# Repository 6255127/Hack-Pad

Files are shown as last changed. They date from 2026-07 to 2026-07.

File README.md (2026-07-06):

# Hackpad

A custom 3x4 macro keyboard I built from scratch - schematic, PCB, 3D printed case, and firmware, all done by me as a portfolio/hackathon project. Built around an Arduino Nano RP2040 Connect, with a rotary encoder, OLED status screen, and per-key RGB backlighting.

## Features
- 3x4 key matrix (12 keys)
- rotary encoder for scroll/navigation
- 0.91" OLED showing current layer, last key pressed, and time (synced over wifi)
- SK6812 addressable LEDs under each key
- two layers - numpad mode and a shortcuts mode (copy/paste/undo/save/etc)
- wired usb keyboard (bluetooth planned later, board already supports it)

---

## 1. Schematic

Designed in KiCad. Went through a few pin conflicts along the way (accidentally put the LED data line on the I2C bus at one point) before landing on the final wiring.



---

## 2. PCB routing

Routed as a 2-layer board - rows on the bottom copper, columns on top, vias where they cross. Ran into a mixed-up switch numbering issue during routing that caused some real weird ratsnest jumps, fixed by re-checking every switch against the row/column table by hand.



---

## 3. 3D case

Modeled in Fusion 360 / Onshape, sandwich-mount style. Bottom half holds the PCB and MCU, top half is the switch plate with cutouts for keycaps, the encoder, and the OLED window. Top plate designed to be printed in clear/frosted material so the LEDs glow through it.



---

## 4. Firmware

Written in Arduino for the Nano RP2040 Connect. Handles matrix scanning, encoder input, LED feedback, OLED display, and layer switching (numpad vs shortcuts) via the encoder click.



---

## To-do
- bluetooth (board already has the chip, just needs the firmware side)
- battery + charging circuit
- silkscreen art on the back

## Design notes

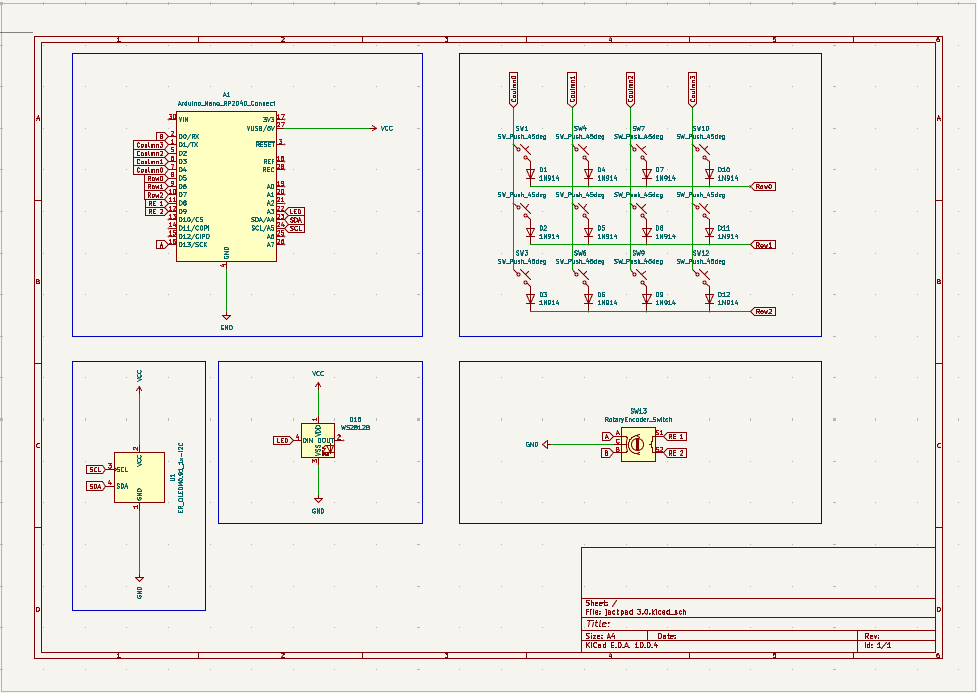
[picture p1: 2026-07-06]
Images/Screenshot 2026-07-04 172658.png

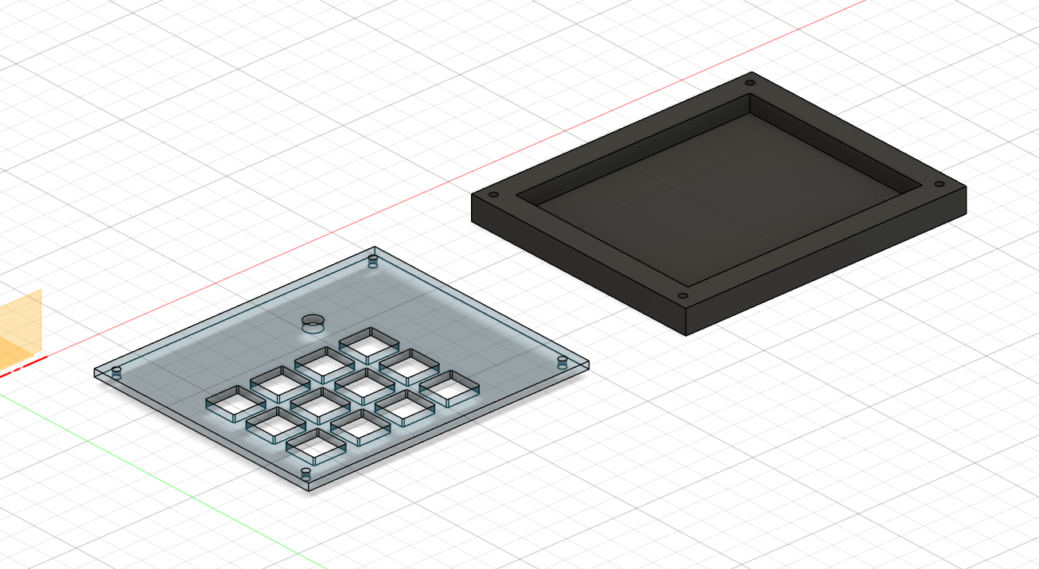
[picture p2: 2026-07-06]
Images/Screenshot 2026-07-05 164234.png

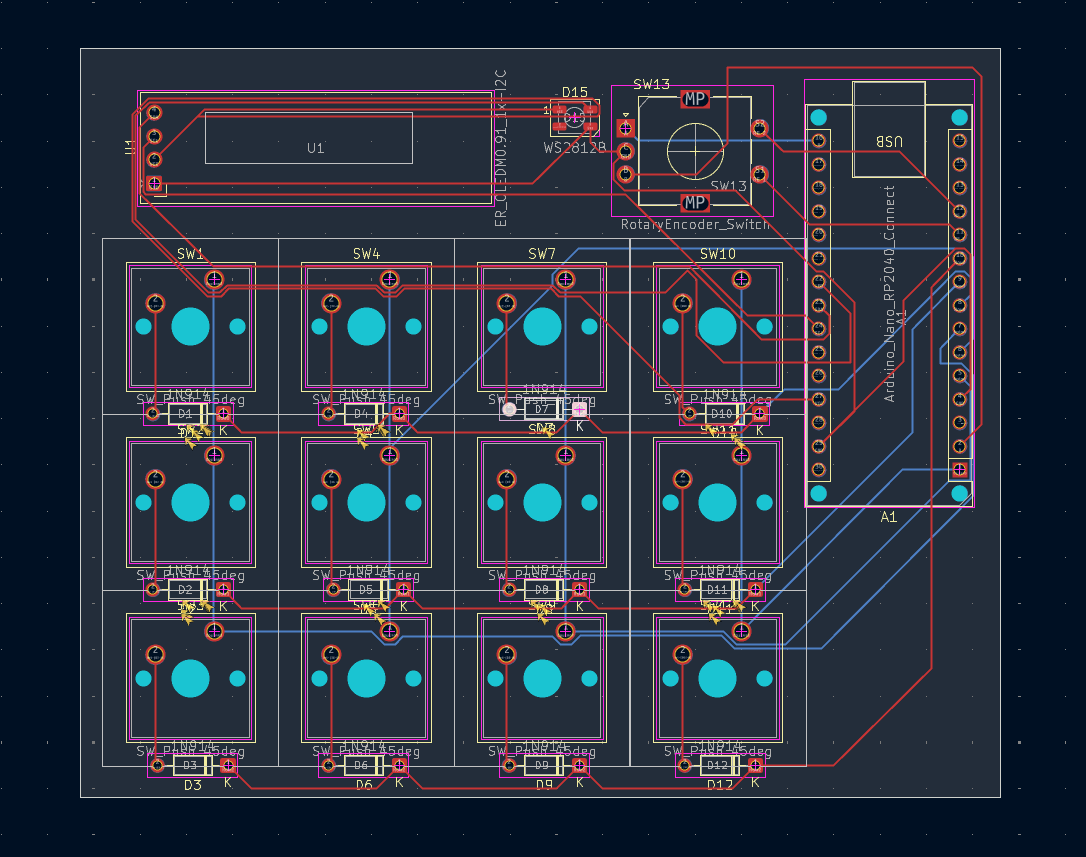
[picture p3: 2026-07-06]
Images/Screenshot 2026-07-05 093806.png

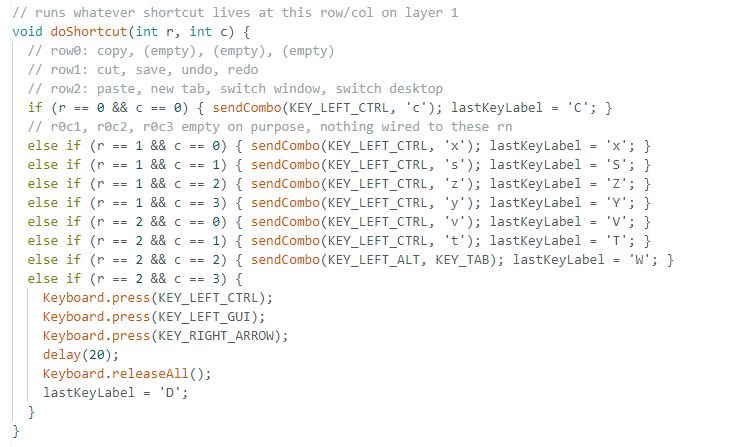
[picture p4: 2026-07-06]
Images/Screenshot 2026-07-06 135348.png

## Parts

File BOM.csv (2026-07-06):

Ref | Part | Qty
A1 | Arduino Nano RP2040 Connect | 1
SW1-SW12 | MX style mechanical switch | 12
D1-D12 | 1N4148 diode (through hole) | 12
ENC1 | EC11 rotary encoder | 1
U1 | 0.91in SSD1306 OLED I2C | 1
LED1-LED12 | SK6812 MINI-E | 12
R1-R2 | 4.7k ohm resistor | 2
future upgrade | LiPo battery 3.7V | 1
future upgrade | TP4056 charge/boost module | 1
 | M3 screws + standoffs | 8
 | keycaps (shine-through) | 12

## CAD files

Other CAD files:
3D/Hackpad.f3d

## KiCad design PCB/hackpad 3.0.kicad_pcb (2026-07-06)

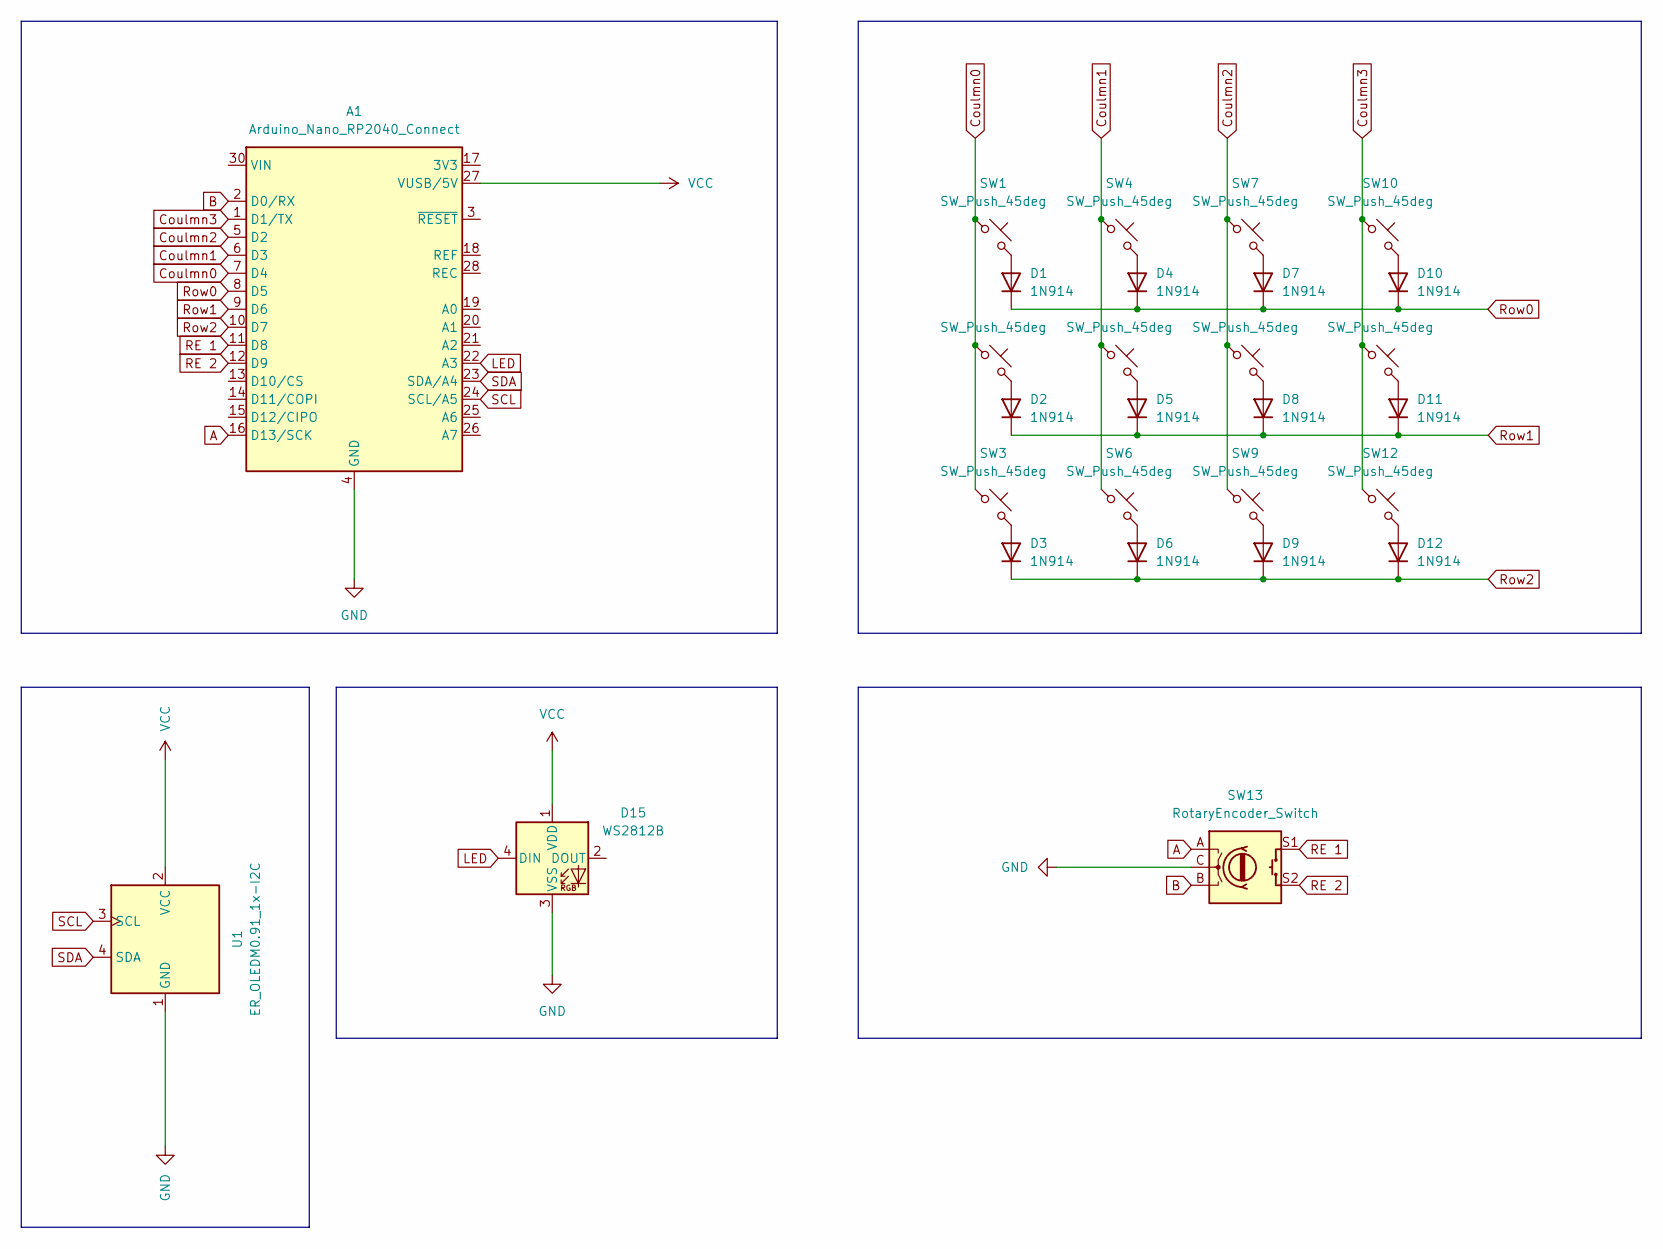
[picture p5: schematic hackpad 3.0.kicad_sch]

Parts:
A1: Arduino_Nano_RP2040_Connect; Arduino_Nano_WithMountingHoles
D1, D2, D3, D4, D5, D6, D7, D8, D9, D10, D11, D12: 1N914; D_DO-35_SOD27_P7.62mm_Horizontal
D15: WS2812B; LED_WS2812B-Mini_PLCC4_3.5x3.5mm
SW1, SW2, SW3, SW4, SW5, SW6, SW7, SW8, SW9, SW10, SW11, SW12: SW_Push_45deg; SW_Cherry_MX_1.00u_PCB
SW13: RotaryEncoder_Switch; RotaryEncoder_Alps_EC11E-Switch_Vertical_H20mm
U1: ER_OLEDM0.91_1x-I2C

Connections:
A: A1.16 (D13/SCK), SW13.A
B: A1.2 (D0/RX), SW13.B
Coulmn0: A1.7 (D4), SW1.1, SW2.1, SW3.1
Coulmn1: A1.6 (D3), SW4.1, SW5.1, SW6.1
Coulmn2: A1.5 (D2), SW7.1, SW8.1, SW9.1
Coulmn3: A1.1 (D1/TX), SW10.1, SW11.1, SW12.1
GND: A1.4 (GND), A1.29 (GND), D15.3 (VSS), SW13.C, U1.1 (GND)
LED: A1.22 (A3), D15.4 (DIN)
unnamed: D1.2 (A), SW1.2
unnamed: D2.2 (A), SW2.2
unnamed: D3.2 (A), SW3.2
unnamed: D4.2 (A), SW4.2
unnamed: D5.2 (A), SW5.2
unnamed: D6.2 (A), SW6.2
unnamed: D7.2 (A), SW7.2
unnamed: D8.2 (A), SW8.2
unnamed: D9.2 (A), SW9.2
unnamed: D10.2 (A), SW10.2
unnamed: D11.2 (A), SW11.2
unnamed: D12.2 (A), SW12.2
RE 1: A1.11 (D8), SW13.S1
RE 2: A1.12 (D9), SW13.S2
Row0: A1.8 (D5), D1.1 (K), D4.1 (K), D7.1 (K), D10.1 (K)
Row1: A1.9 (D6), D2.1 (K), D5.1 (K), D8.1 (K), D11.1 (K)
Row2: A1.10 (D7), D3.1 (K), D6.1 (K), D9.1 (K), D12.1 (K)
SCL: A1.24 (SCL/A5), U1.3 (SCL)
SDA: A1.23 (SDA/A4), U1.4 (SDA)
VCC: A1.27 (VUSB/5V), D15.1 (VDD), U1.2 (VCC)

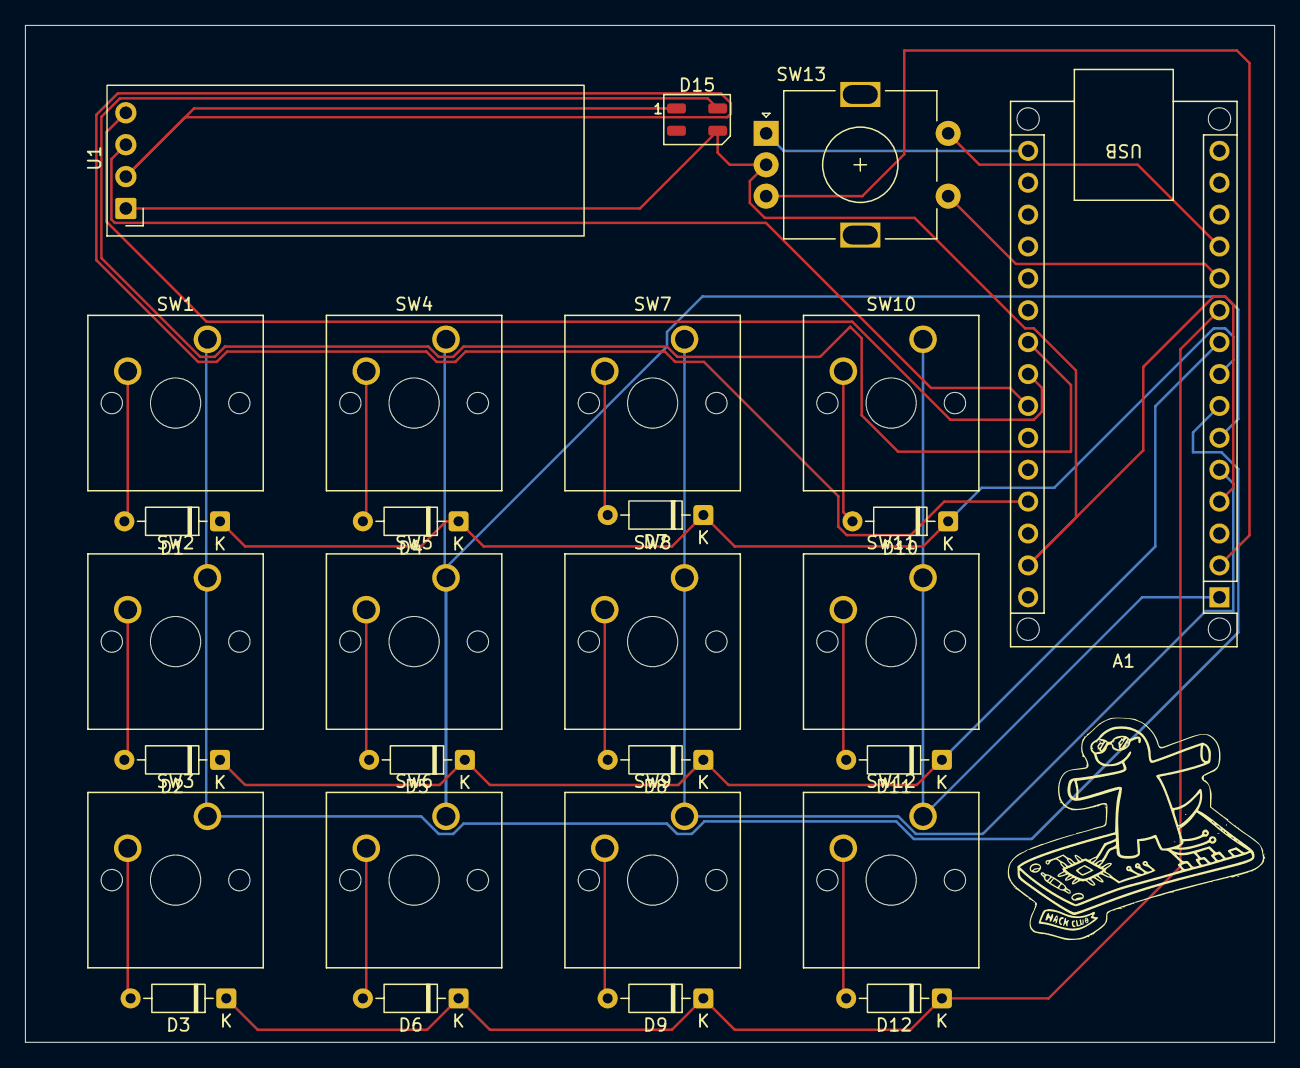
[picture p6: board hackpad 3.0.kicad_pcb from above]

Board: 2 copper layers, 99.5 x 81.0 mm, 28 parts (0 on the bottom side), 28 nets.

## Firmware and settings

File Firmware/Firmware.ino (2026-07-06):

// hackpad firmware v4

#include <Keyboard.h>
#include <Wire.h>
#include <WiFiNINA.h>
#include <Adafruit_GFX.h>
#include <Adafruit_SSD1306.h>
#include <Adafruit_NeoPixel.h>

// change these to your actual wifi so it can grab the time
const char* ssid = "your_wifi_name";
const char* pass = "your_wifi_password";

const int rowPins[3] = {5, 6, 7};
const int colPins[4] = {4, 3, 2, 1};
const int encA = 13;
const int encB = 0;
const int encBtn = 8;

#define LED_PIN A3
#define NUM_LEDS 12
Adafruit_NeoPixel strip(NUM_LEDS, LED_PIN, NEO_GRB + NEO_KHZ800);

#define SCREEN_WIDTH 128
#define SCREEN_HEIGHT 32
Adafruit_SSD1306 display(SCREEN_WIDTH, SCREEN_HEIGHT, &Wire, -1);

char keymap[3][4] = {
  {'7', '8', '9', '/'},
  {'4', '5', '6', '*'},
  {'1', '2', '3', '-'}
};

bool keyState[3][4] = {false};
int lastEncA = HIGH;
int layer = 0;
bool btnWasPressed = false;
char lastKeyLabel = ' ';

unsigned long lastTimeSync = 0;
unsigned long epochAtSync = 0; // unix time from the last successful sync

void setup() {
  Serial.begin(9600);
  Keyboard.begin();

  for (int r = 0; r < 3; r++) {
    pinMode(rowPins[r], OUTPUT);
    digitalWrite(rowPins[r], HIGH);
  }
  for (int c = 0; c < 4; c++) {
    pinMode(colPins[c], INPUT_PULLUP);
  }

  pinMode(encA, INPUT_PULLUP);
  pinMode(encB, INPUT_PULLUP);
  pinMode(encBtn, INPUT_PULLUP);

  strip.begin();
  strip.show();

  if (!display.begin(SSD1306_SWITCHCAPVCC, 0x3C)) {
    Serial.println("oled not found, check wiring");
    while (1);
  }

  // connect to wifi so we can get real time. if this fails clock just
  // stays at --:--:--, everything else still works fine
  WiFi.begin(ssid, pass);
  int tries = 0;
  while (WiFi.status() != WL_CONNECTED && tries < 20) {
    delay(500);
    tries++;
  }
  syncTime();
  updateDisplay();
}

void syncTime() {
  if (WiFi.status() == WL_CONNECTED) {
    unsigned long t = WiFi.getTime(); // nina module handles the ntp stuff
    if (t > 0) {
      epochAtSync = t;
      lastTimeSync = millis();
    }
  }
}

// turns the synced epoch + however long its been since into HH:MM:SS
String getTimeString() {
  if (epochAtSync == 0) return "--:--:--";

  unsigned long secondsNow = epochAtSync + (millis() - lastTimeSync) / 1000;
  int h = (secondsNow % 86400L) / 3600;
  int m = (secondsNow % 3600) / 60;
  int s = secondsNow % 60;

  char buf[9];
  sprintf(buf, "%02d:%02d:%02d", h, m, s);
  return String(buf);
}

void updateDisplay() {
  display.clearDisplay();
  display.setTextSize(1);
  display.setTextColor(SSD1306_WHITE);
  display.setCursor(0, 0);
  display.println(getTimeString());
  display.print("layer: ");
  display.println(layer == 0 ? "numpad" : "shortcuts");
  display.print("last: ");
  display.println(lastKeyLabel);
  display.display();
}

void sendCombo(int mod, int key) {
  Keyboard.press(mod);
  Keyboard.press(key);
  delay(20);
  Keyboard.releaseAll();
}

// runs whatever shortcut lives at this row/col on layer 1
void doShortcut(int r, int c) {
  // row0: copy, (empty), (empty), (empty)
  // row1: cut, save, undo, redo
  // row2: paste, new tab, switch window, switch desktop
  if (r == 0 && c == 0) { sendCombo(KEY_LEFT_CTRL, 'c'); lastKeyLabel = 'C'; }
  // r0c1, r0c2, r0c3 empty on purpose, nothing wired to these rn
  else if (r == 1 && c == 0) { sendCombo(KEY_LEFT_CTRL, 'x'); lastKeyLabel = 'x'; }
  else if (r == 1 && c == 1) { sendCombo(KEY_LEFT_CTRL, 's'); lastKeyLabel = 'S'; }
  else if (r == 1 && c == 2) { sendCombo(KEY_LEFT_CTRL, 'z'); lastKeyLabel = 'Z'; }
  else if (r == 1 && c == 3) { sendCombo(KEY_LEFT_CTRL, 'y'); lastKeyLabel = 'Y'; }
  else if (r == 2 && c == 0) { sendCombo(KEY_LEFT_CTRL, 'v'); lastKeyLabel = 'V'; }
  else if (r == 2 && c == 1) { sendCombo(KEY_LEFT_CTRL, 't'); lastKeyLabel = 'T'; }
  else if (r == 2 && c == 2) { sendCombo(KEY_LEFT_ALT, KEY_TAB); lastKeyLabel = 'W'; }
  else if (r == 2 && c == 3) {
    Keyboard.press(KEY_LEFT_CTRL);
    Keyboard.press(KEY_LEFT_GUI);
    Keyboard.press(KEY_RIGHT_ARROW);
    delay(20);
    Keyboard.releaseAll();
    lastKeyLabel = 'D';
  }
}

void scanMatrix() {
  for (int r = 0; r < 3; r++) {
    digitalWrite(rowPins[r], LOW);

    for (int c = 0; c < 4; c++) {
      bool pressed = digitalRead(colPins[c]) == LOW;
      int ledIndex = r * 4 + c;

      if (pressed && !keyState[r][c]) {
        keyState[r][c] = true;
        strip.setPixelColor(ledIndex, strip.Color(0, 100, 200));
        strip.show();

        if (layer == 0) {
          Keyboard.press(keymap[r][c]);
          lastKeyLabel = keymap[r][c];
        } else {
          doShortcut(r, c);
        }
        updateDisplay();

      } else if (!pressed && keyState[r][c]) {
        keyState[r][c] = false;
        strip.setPixelColor(ledIndex, 0);
        strip.show();
        if (layer == 0) Keyboard.release(keymap[r][c]);
      }
    }

    digitalWrite(rowPins[r], HIGH);
  }
}

void checkEncoder() {
  int a = digitalRead(encA);
  if (a != lastEncA && a == LOW) {
    int b = digitalRead(encB);
    if (b != a) Keyboard.write(KEY_UP_ARROW);
    else Keyboard.write(KEY_DOWN_ARROW);
  }
  lastEncA = a;

  bool btnPressed = digitalRead(encBtn) == LOW;
  if (btnPressed && !btnWasPressed) {
    layer = 1 - layer;
    updateDisplay();
    delay(200);
  }
  btnWasPressed = btnPressed;
}

void loop() {
  scanMatrix();
  checkEncoder();

  // resync every hour so the clock doesnt slowly drift off
  if (millis() - lastTimeSync > 3600000UL) {
    syncTime();
  }

  // just refresh the clock display once a second when nothing else going on
  static unsigned long lastTick = 0;
  if (millis() - lastTick > 1000) {
    lastTick = millis();
    updateDisplay();
  }
}

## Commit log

2026-07-06 Update README with project details and features
    Added detailed project description, features, and sections for schematic, PCB routing, 3D case, firmware, and to-do list.
2026-07-06 reorganized folder structure
    [Hackpad.f3d, Hackpad.kicad_pcb, hackpad 3.0.kicad_pcb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]
